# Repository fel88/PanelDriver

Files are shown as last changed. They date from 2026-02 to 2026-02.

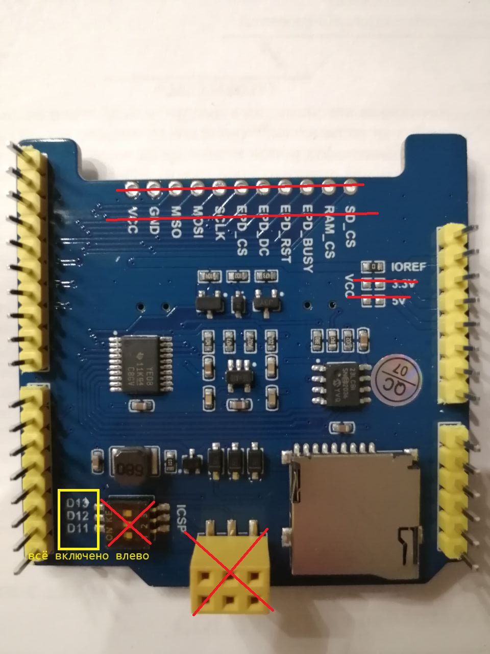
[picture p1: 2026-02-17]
docs/shield6.jpg

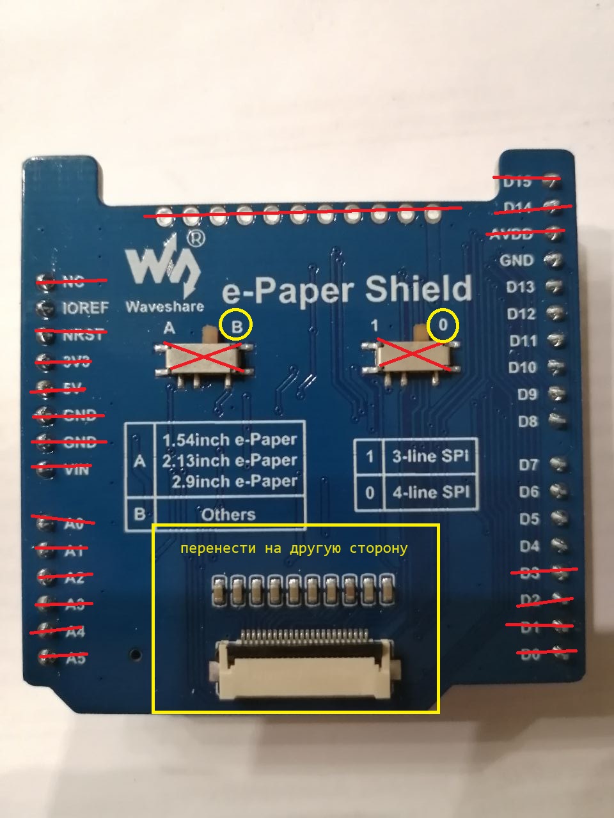
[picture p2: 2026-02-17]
docs/shield5.png

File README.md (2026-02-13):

# PanelDriver
Arduino Mega 2560 Embed + Waveshare e-ink universal shield



<h2>Parts:</h2>




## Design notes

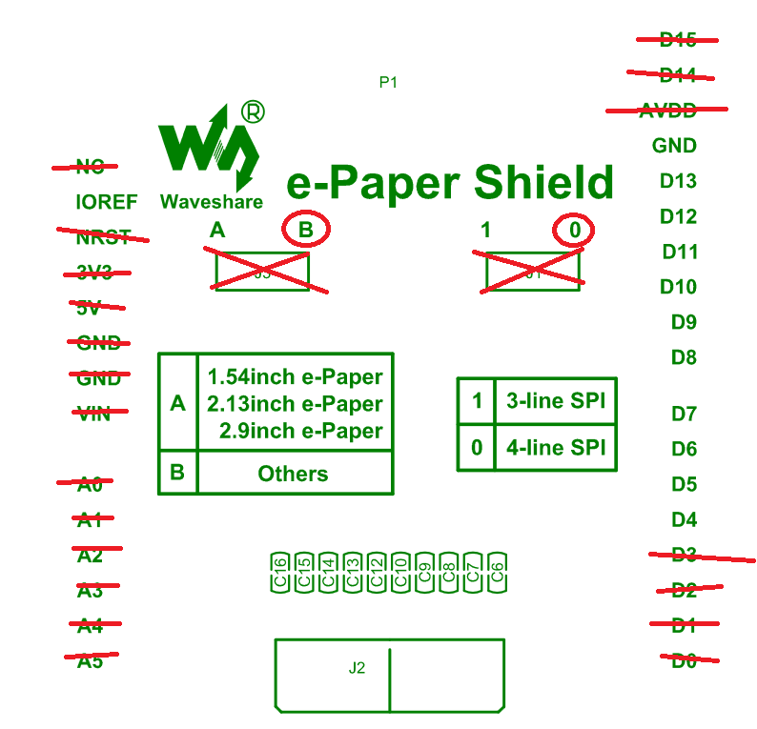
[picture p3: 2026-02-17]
docs/shield1.png

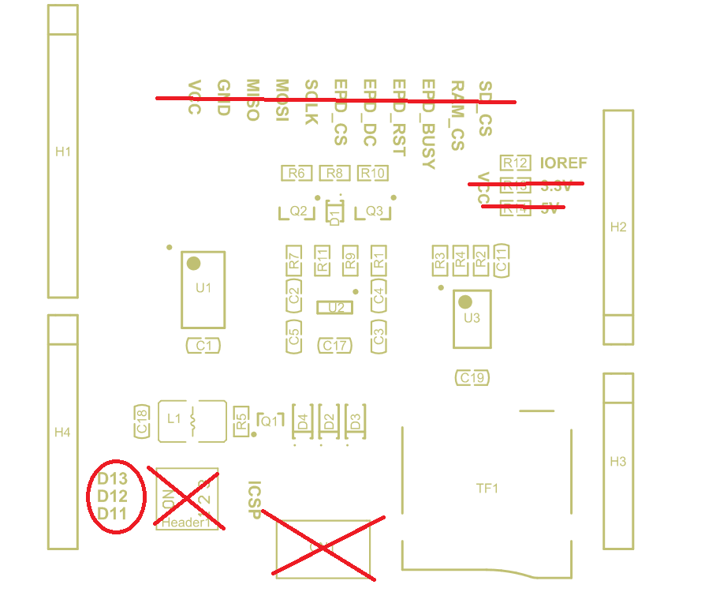
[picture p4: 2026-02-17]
docs/shield2.png

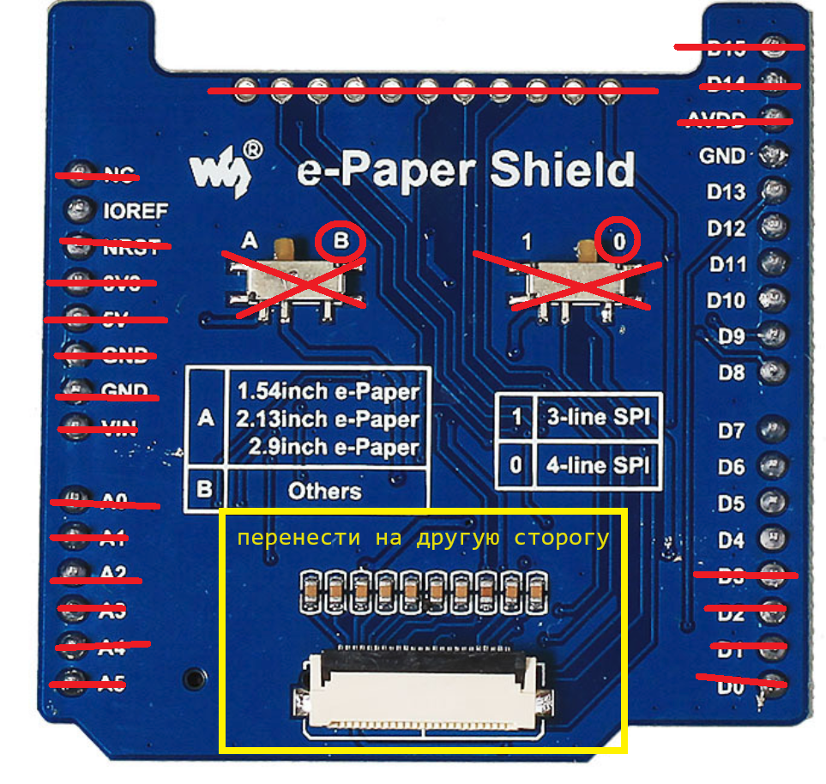
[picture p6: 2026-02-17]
docs/shield3.png

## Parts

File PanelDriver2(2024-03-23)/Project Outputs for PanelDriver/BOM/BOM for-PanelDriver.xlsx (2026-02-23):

 | Component list
 | Name: | PanelDriver.PrjPcb
 | PCB Rev: | <Parameter RevisionPCB not found>
 | BOM Variant: | None
 | Report Date: | 23.03.2024
 | Designator | Quantity | Footprint | Comment | Manufacturer | Manufacturer Part Number | Description
1 | C1, C12, C13, C18 | 4 | C0603 | 100nF | Any | Any | Capacitor
2 | C2, C3, C4, C5, C6, C7, C8, C10, C11, C14 | 10 | C0603 | 1uF | Any | Any | Capacitor
3 | C9 | 1 | C0603 | 4.7uF | Any | Any | Capacitor
4 | C15, C19 | 2 | C0603 | 100n | Any | Any | Capacitor
5 | C16 | 1 | C0603 | 22nF | Any | Any | Capacitor
6 | C17 | 1 | C0603 | 10uF | Any | Any | Capacitor
7 | C20 | 1 | C1206 | 22uF | Any | Any | 16V 22uF X7R ±10% 1206 Multilayer Ceramic Capacitors MLCC - SMD/SMT ROHS
8 | C21, C24, C25, C26, C27, C28, C29 | 7 | C0603 | 0.1uF | Any | Any | 25V 100nF X7R ±10% 0603 Multilayer Ceramic Capacitors MLCC - SMD/SMT ROHS
9 | C22, C23 | 2 | C0603 | 12pF | Any | Any | 50V 22pF X7R ±10% 0603 Multilayer Ceramic Capacitors MLCC - SMD/SMT ROHS
10 | D1, D2, D3 | 3 | SOD123 | MBR0530 | Any | MBR0530 | MBR0530
11 | D4 | 1 | SOD-323 | 1N4148WS | Any | 1N4148WS | 1N4148WS
12 | D5 | 1 | SOD123 | 1N4148W | Any | Any | 1N4148W-E3-08, Rectifier Diode Small Signal Switching Si 100V 0.15A 4ns 2-Pin SOD-123 T/R
13 | J1 | 1 | PFC24/0.5MM | PFC24/0.5MM | MOLEX | 524372471 | 24 Position FFC, FPC Connector Contacts, Bottom 0.020" (0.50mm) Surface Mount, Right Angle
14 | L1 | 1 | CD43 | 68uH | Any | Any | SMD, 4x4mm Inductor
15 | LED1, LED2, LED3, LED4 | 4 | LED-0603-GREEN | GREEN | Any | Any | 0603 Light Emitting Diodes (LED) ROHS
16 | P1, P2 | 2 | HDR1X2 | Header 2 |  |  | Header, 2-Pin
17 | P3, P4, P5 | 3 | HDR1X4 | Header 4 |  |  | Header, 4-Pin
18 | P6 | 1 | HDR1X5 | Header 5 | Any | Any | Header, 5-Pin
19 | P7 | 1 | HDR1X16 | Header 16 |  |  | Header, 16-Pin
20 | Q1 | 1 | SOT323-3 | Si1308EDL | Any | Si1308EDL | Si1308EDL
21 | Q2 | 1 | SOT-23 | AO3401 | Any | AO3401 | AO3401
22 | Q3 | 1 | SOT-23 | S8050 | Any | S8050 | S8050
23 | R1, R14, R17 | 3 | R0603 | 10k | Any | Any | Resistor, 125mW Thick Film Resistors ±100ppm/℃ ±5% 10kΩ 0603 Chip Resistor - Surface Mount ROHS
24 | R2 | 1 | R0603 | 3R | Any | Any | Resistor
25 | R3, R4, R9, R10, R13 | 5 | R0603 | 1k | Any | Any | Resistor, 125mW Thick Film Resistors ±100ppm/℃ ±5% 1kΩ 0603 Chip Resistor - Surface Mount ROHS
26 | R5, R7 | 2 | R0603 | 47k | Any | Any | Resistor
27 | R6, R8 | 2 | R0603 | 100k | Any | Any | Resistor
28 | R11, R12 | 2 | R0603 | 6.8k | Any | Any | 125mW Thick Film Resistors ±100ppm/℃ ±5% 6.8kΩ 0603 Chip Resistor - Surface Mount ROHS
29 | R15, R16 | 2 | R0603 | 22 | Any | Any | 125mW Thick Film Resistors ±100ppm/℃ ±5% 22Ω 0603 Chip Resistor - Surface Mount ROHS
30 | R18 | 1 | R0603 | 1M | Any | Any | 125mW Thick Film Resistors ±100ppm/℃ ±5% 1M 0603 Chip Resistor - Surface Mount ROHS
31 | TF1 | 1 | L-KLS1-TF-003-uSD | SD CARD | KLS electronic co ltd | L-KLS1-TF-003-uSD | SDCARD
32 | U1 | 1 | TSSOP-20_0.65mm | TXS0108EPWR | Any | TXS0108EPWR | TXS0108EPWR
33 | U2 | 1 | SO8 | 23LC1024 | Any | 23LC1024 | 23LC1024
34 | U3 | 1 | SOT23-5 | RT9193 | Any | RT9193 | RT9193
35 | U4 | 1 | TQFP100A | ATMEGA2560-16AU | Microchip Tech | ATMEGA2560-16AU | 256KB 4.5V~5.5V AVR 8KB 16MHz FLASH 86 TQFP-100(14x14) Microcontroller Units (MCUs/MPUs/SOCs) ROHS
36 | Y1 | 1 | HC-49/US-SMD | 16MHz | Any | Any | Crystal 16MHz 12pF SMD
 | TOTAL PART COUNT: | 74

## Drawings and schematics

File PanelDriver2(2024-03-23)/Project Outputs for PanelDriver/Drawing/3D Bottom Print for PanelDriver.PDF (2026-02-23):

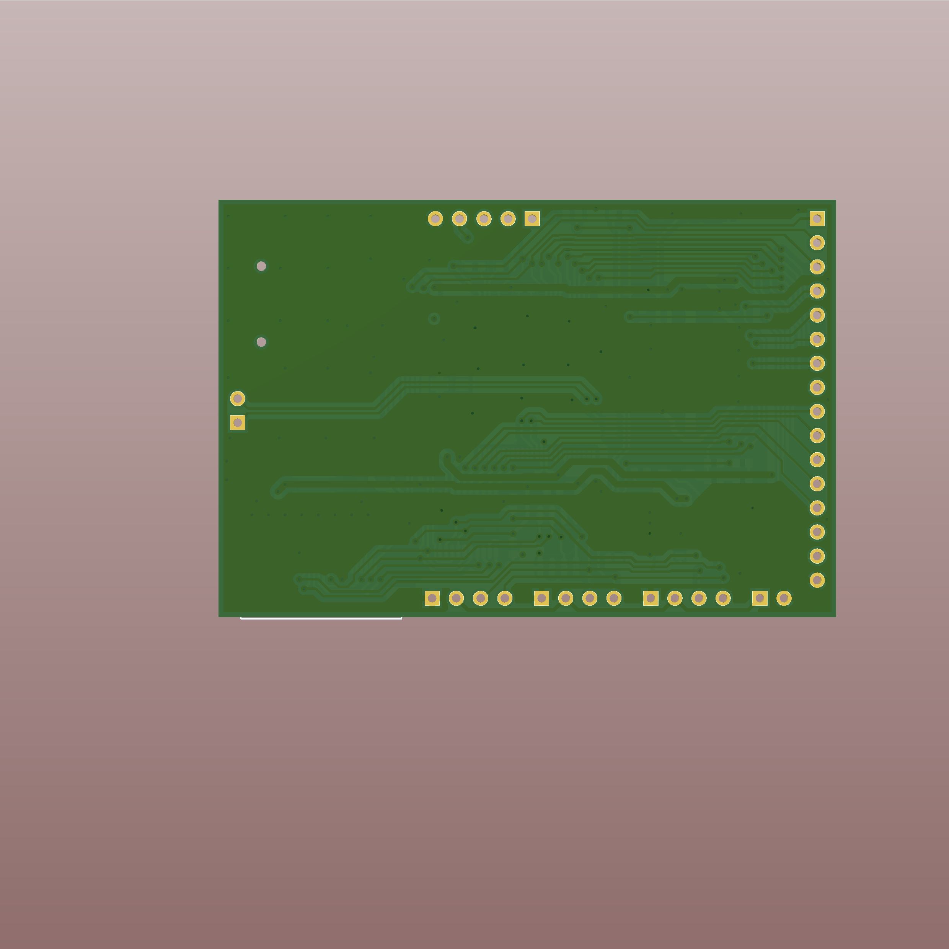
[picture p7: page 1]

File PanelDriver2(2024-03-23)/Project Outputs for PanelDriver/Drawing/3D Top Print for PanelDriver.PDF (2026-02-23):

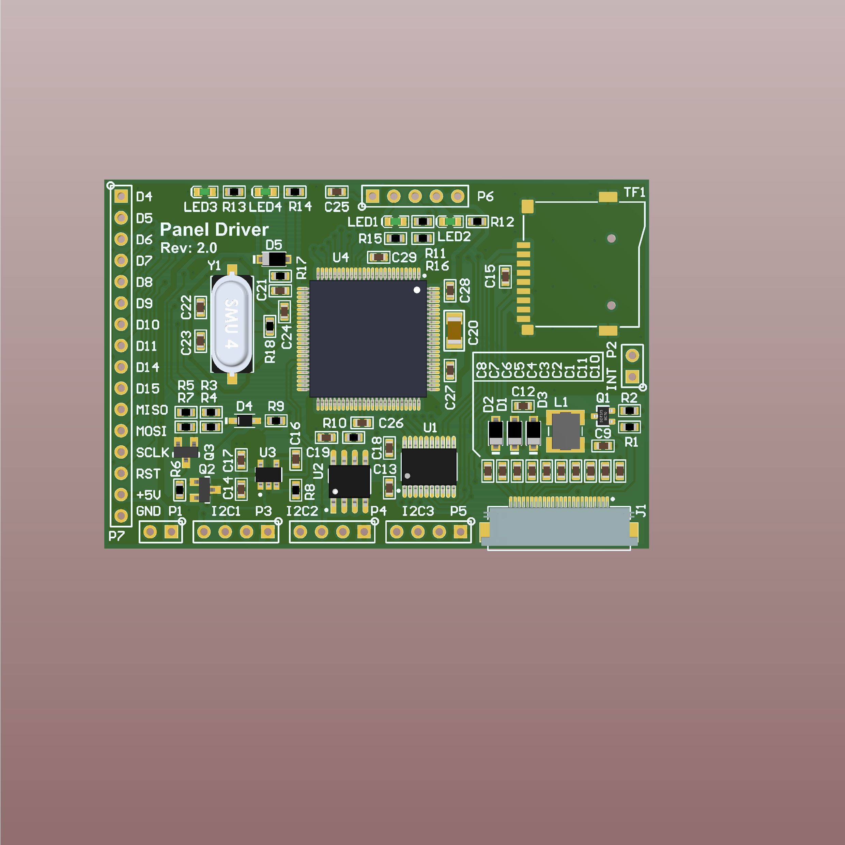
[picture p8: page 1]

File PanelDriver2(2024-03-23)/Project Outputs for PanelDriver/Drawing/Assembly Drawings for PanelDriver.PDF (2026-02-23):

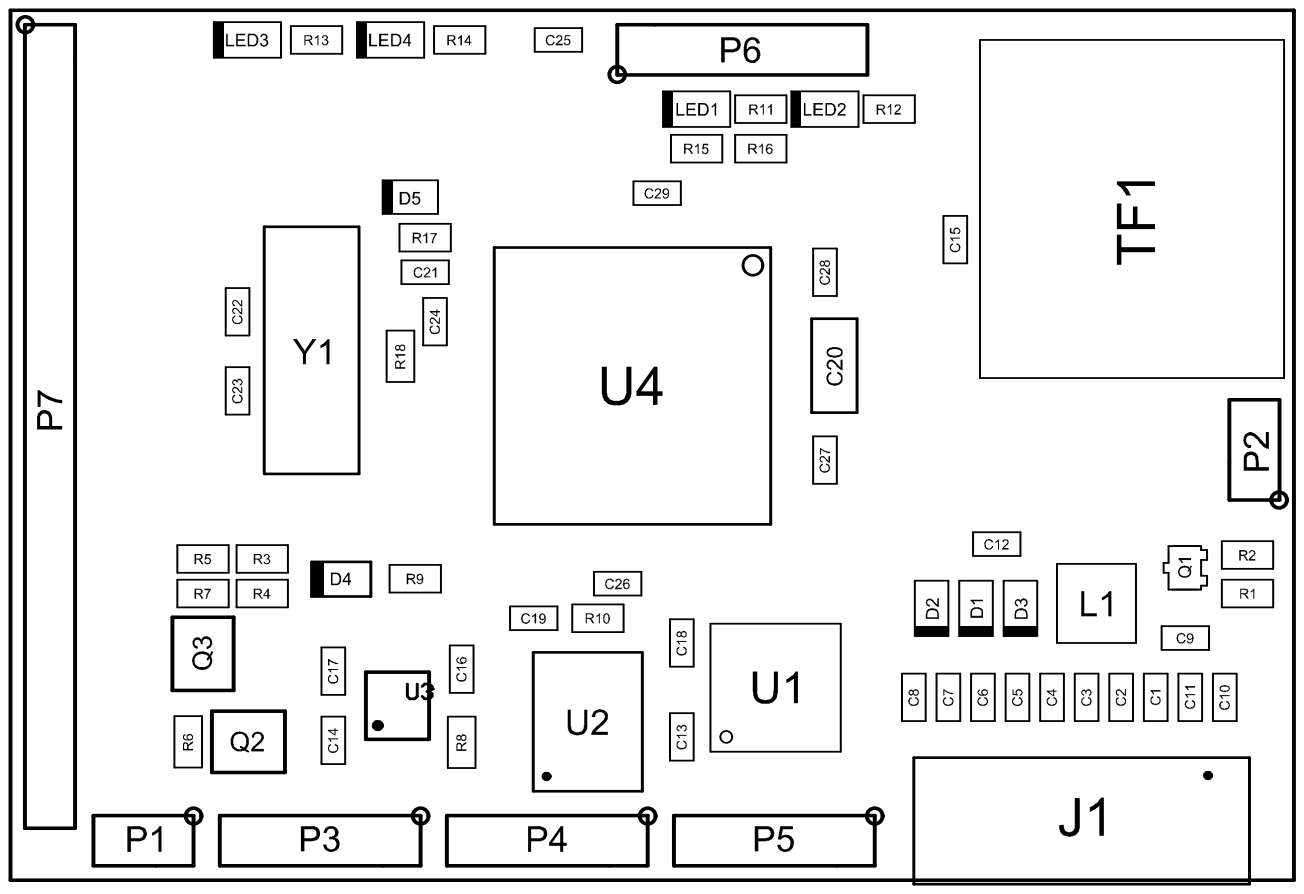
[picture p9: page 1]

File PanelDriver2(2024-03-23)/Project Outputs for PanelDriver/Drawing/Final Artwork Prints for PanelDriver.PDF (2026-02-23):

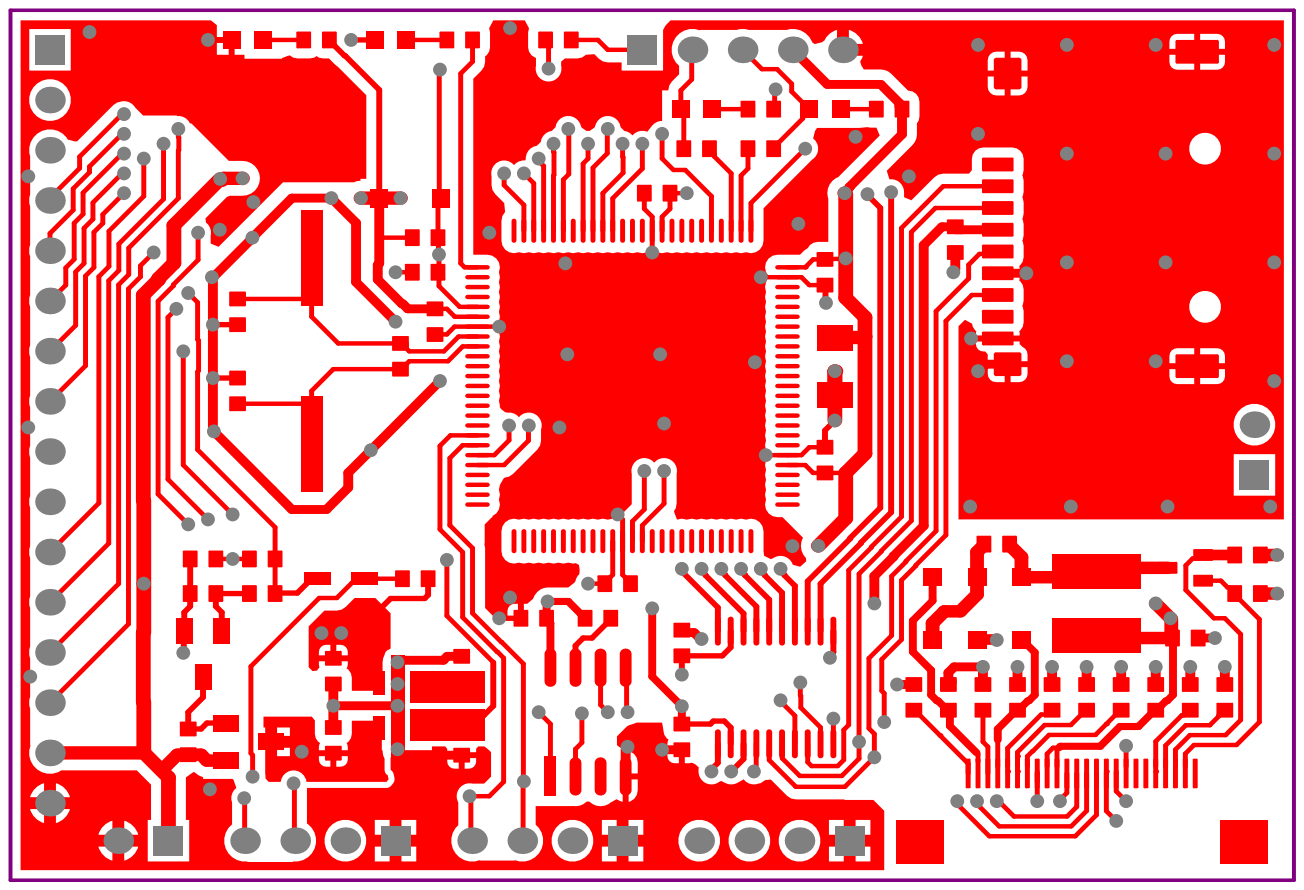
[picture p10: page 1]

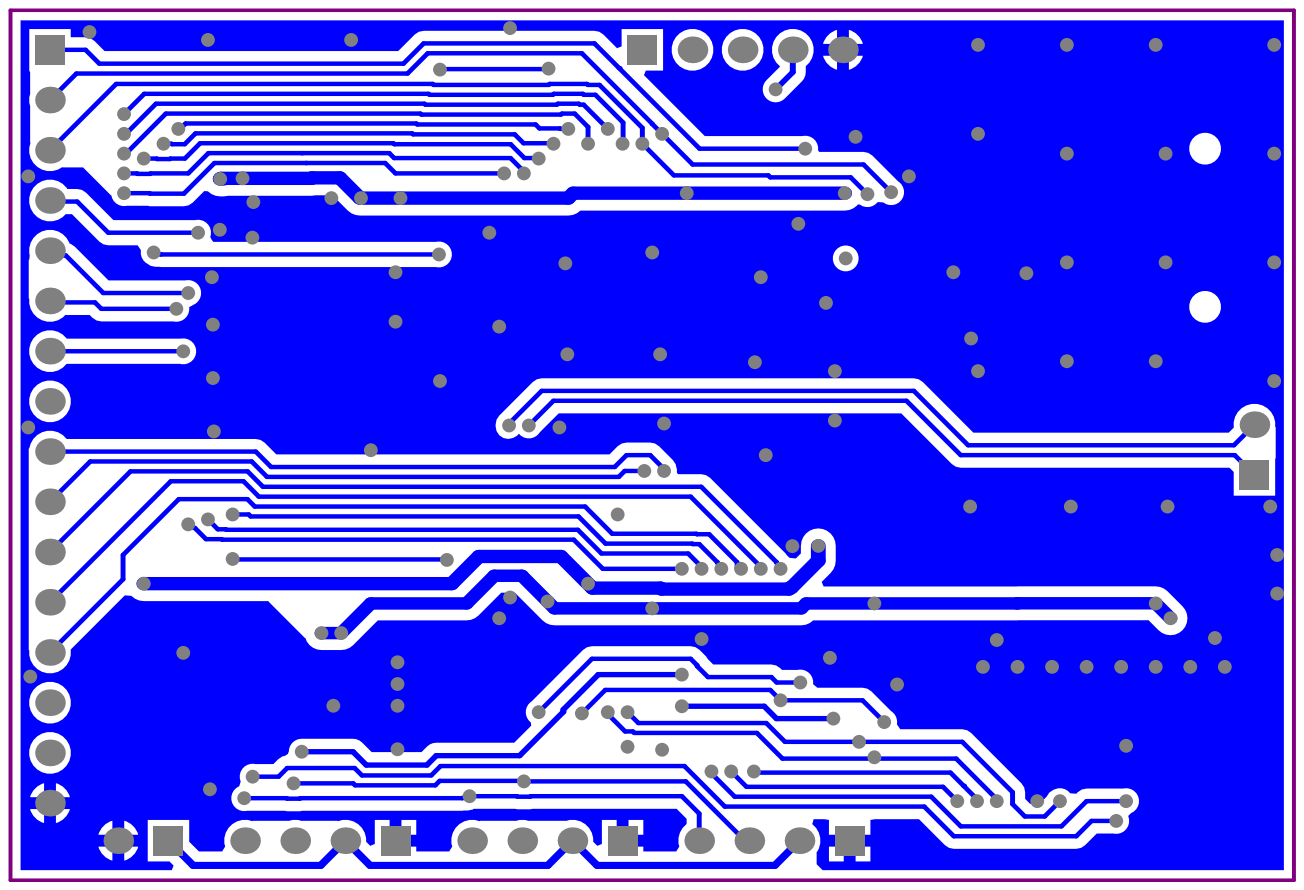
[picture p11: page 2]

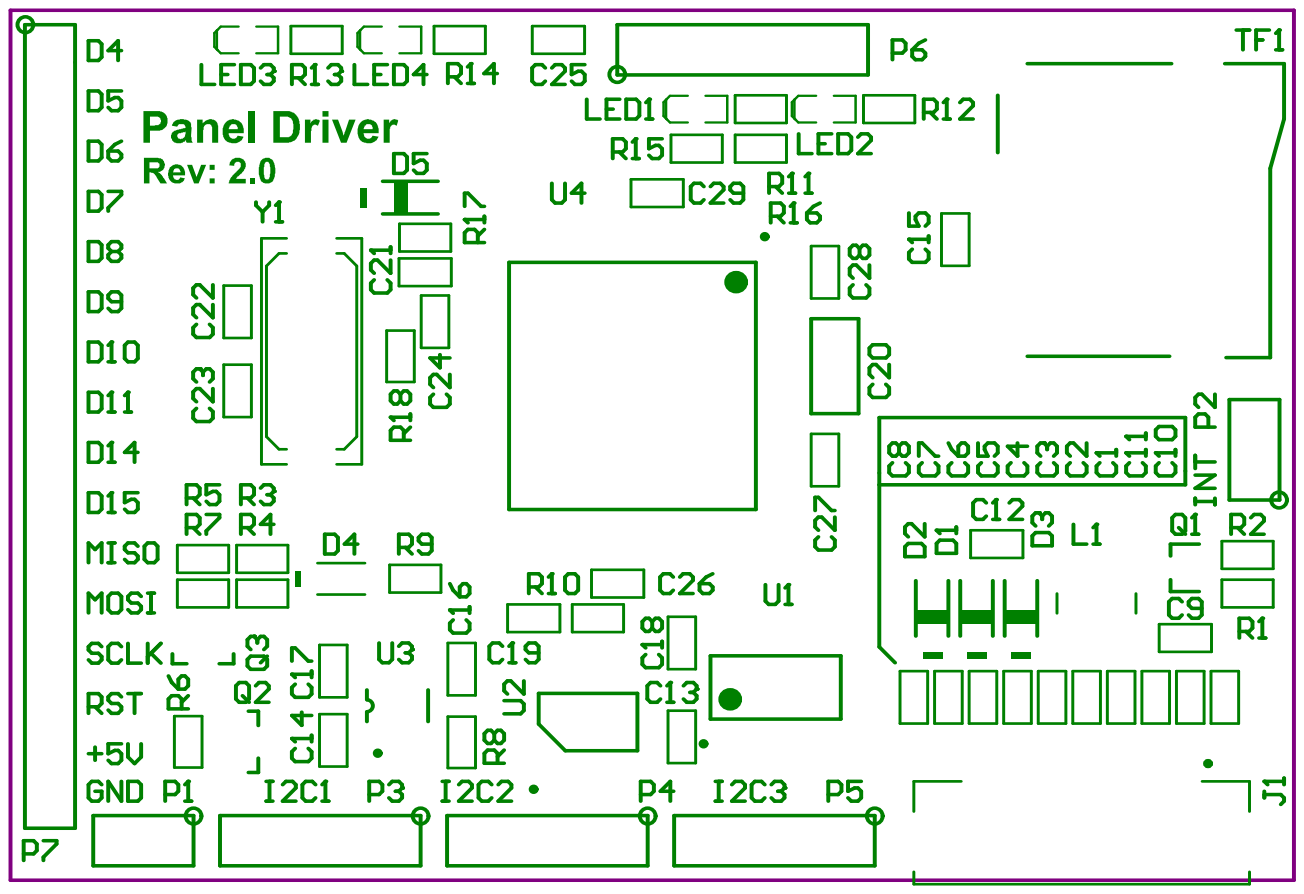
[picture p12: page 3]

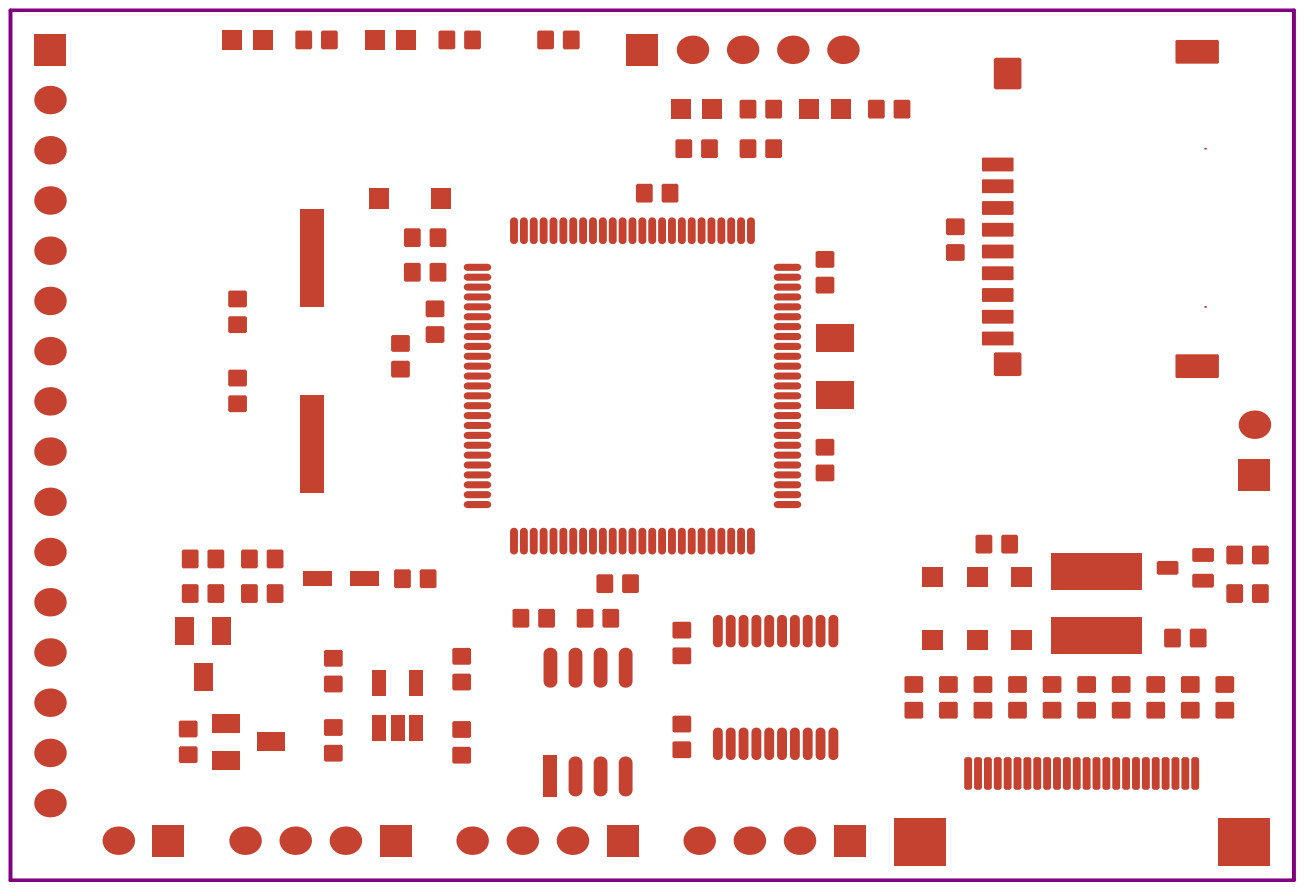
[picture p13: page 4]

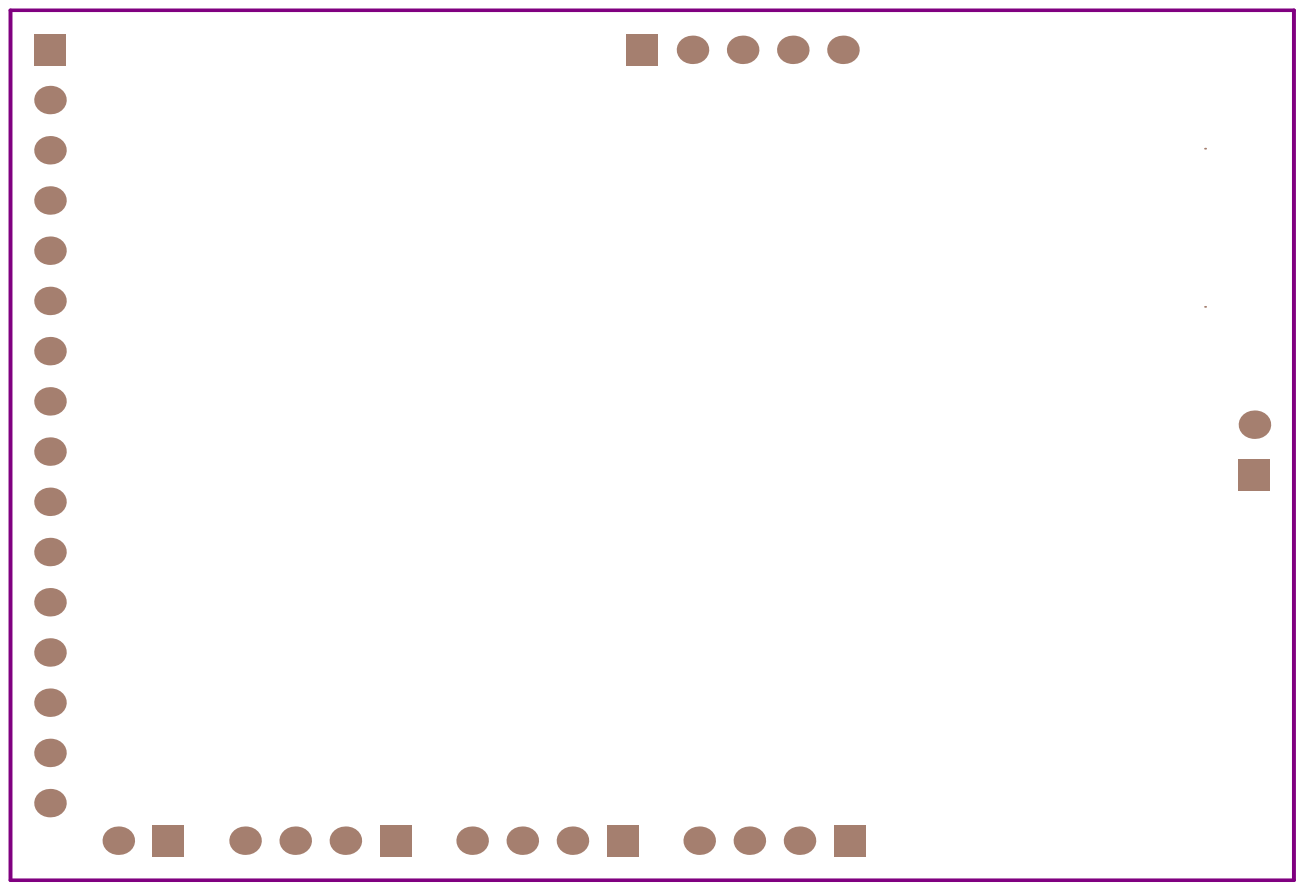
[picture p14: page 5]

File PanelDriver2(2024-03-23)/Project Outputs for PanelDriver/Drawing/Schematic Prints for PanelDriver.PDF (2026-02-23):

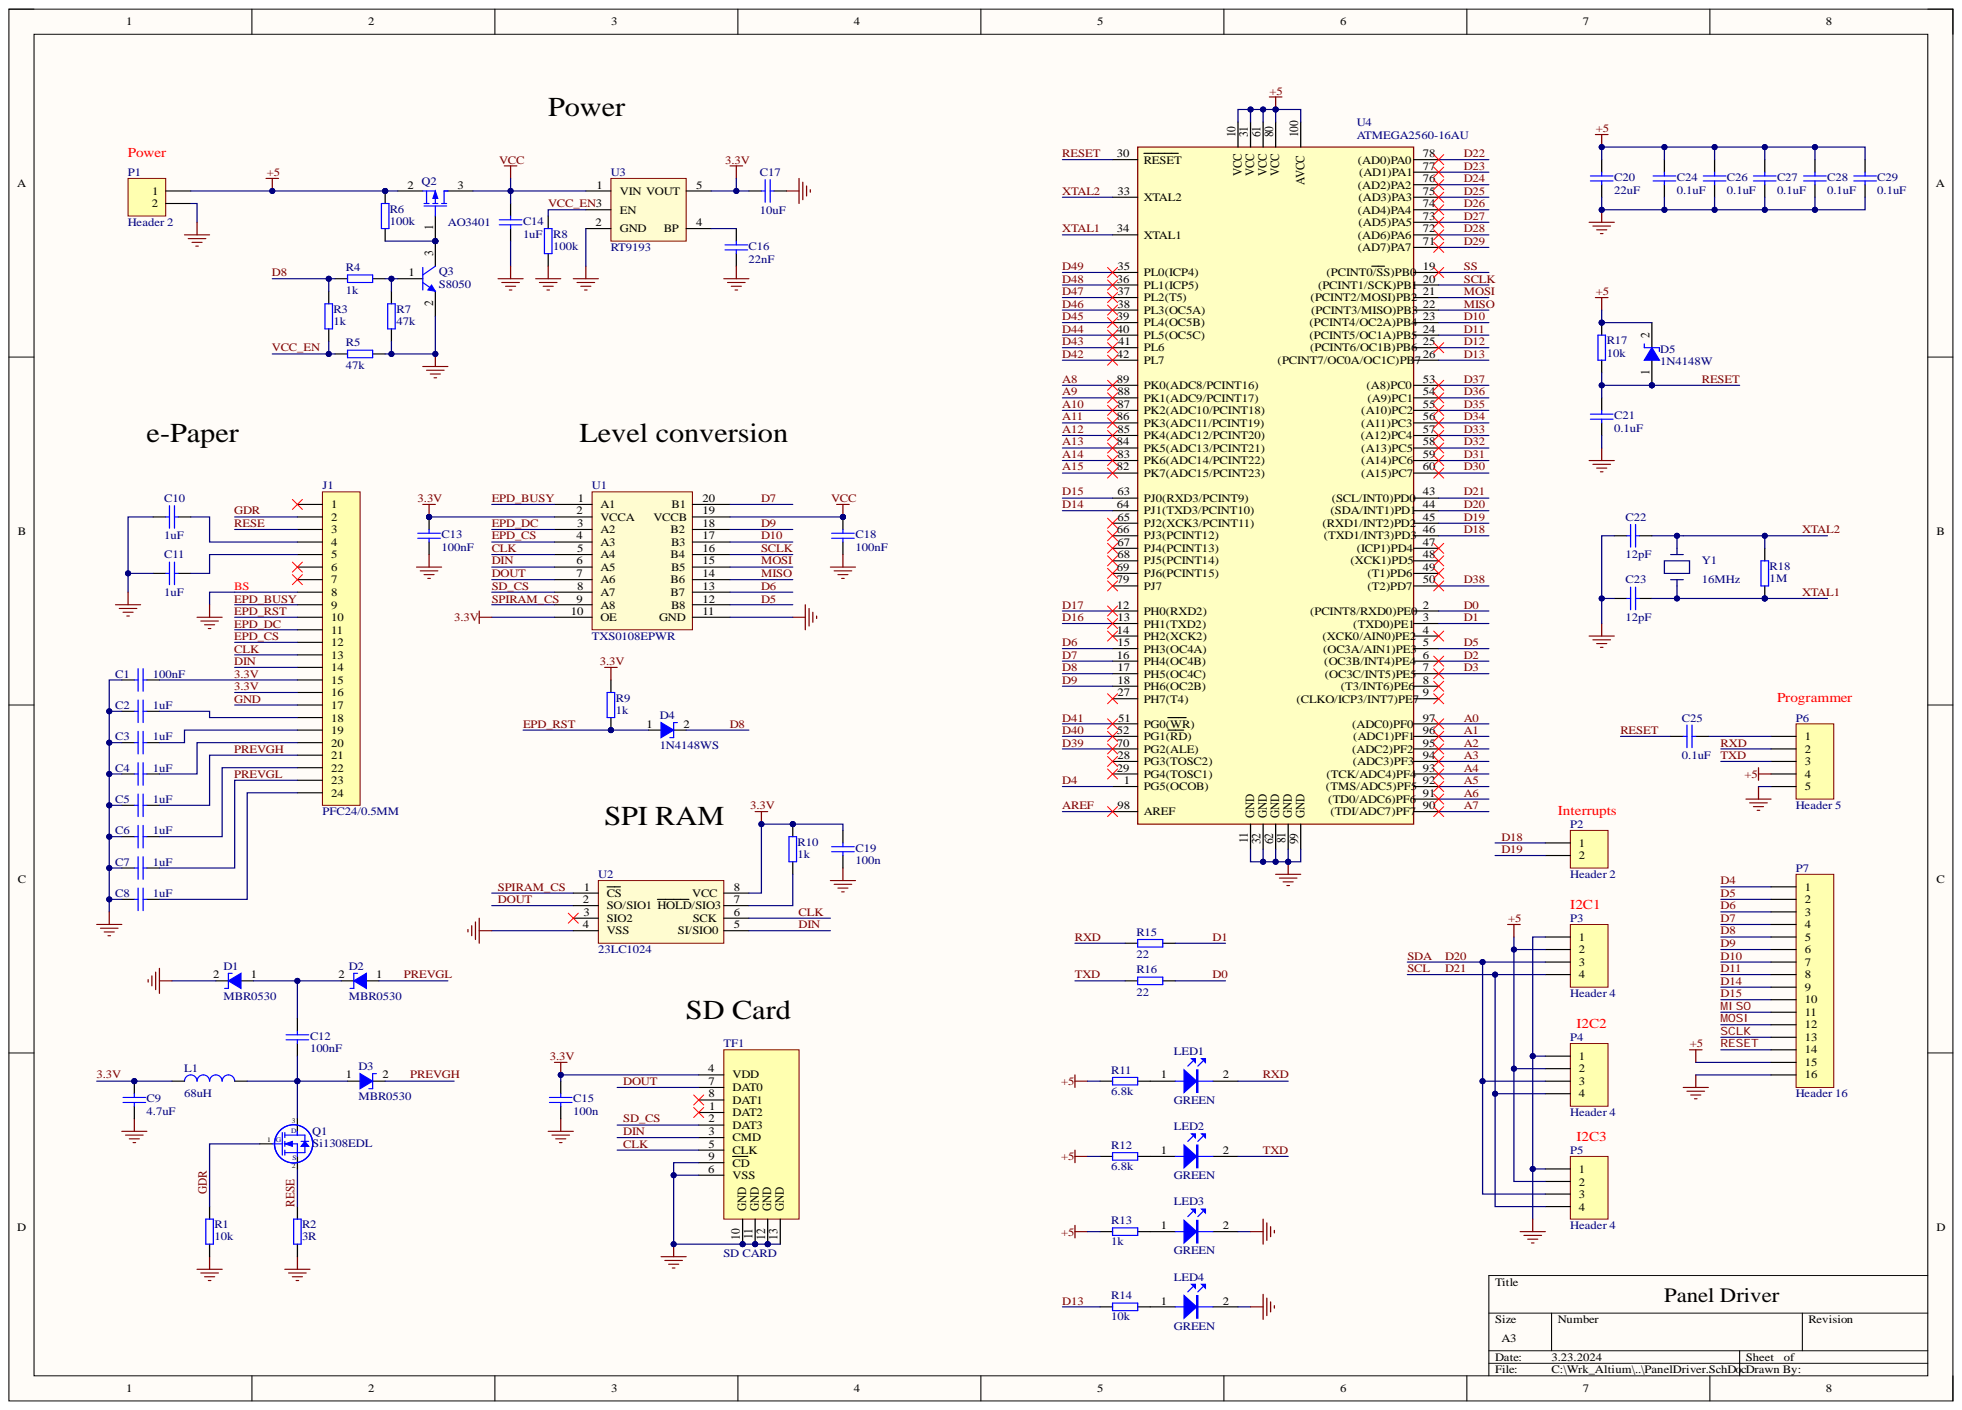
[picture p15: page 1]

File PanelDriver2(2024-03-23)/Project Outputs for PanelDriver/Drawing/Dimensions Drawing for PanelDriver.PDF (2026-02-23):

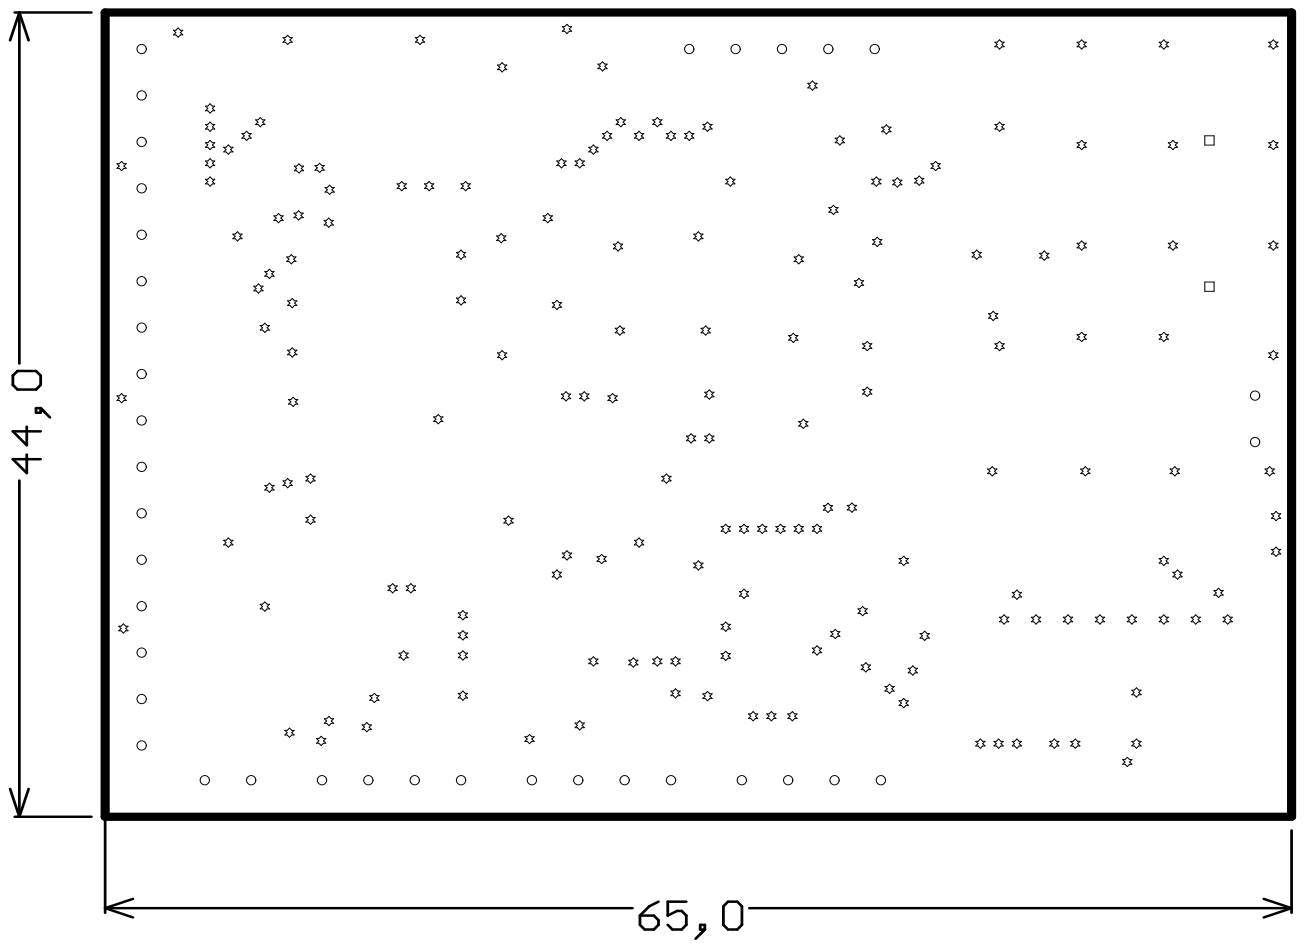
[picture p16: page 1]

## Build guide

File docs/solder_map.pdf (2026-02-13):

Sheet1
panel driver | | waveshare
R10 | 1K | R2
C19 | 100nF C11
C15 | 100nF C19
C1 | 100nF C8
C10 | 1uF | C6
C11 | 1uF | C7
C2 | 1uF | C9
C3 | 1uF | C10
C4 | 1uF | C12
C5 | 1uF | C13
C6 | 1uF | C14
C7 | 1uF | C15
C8 | 1uF | C16
C13 | 100nF C1
C18 | 100nF C2
D4 | | D1
R9 | 1K | R1
U3 | | U2
C17 | | C3
C16 | | C5
R8 | | R7
C14 | | C4
Q2 | | Q2
R6 | | R6
Q3 | | Q3
R4 | | R8
R3 | | R9
R5 | | R11
R7 | | R10
Q1 | | Q1
D3 | | D4
L1 | | L1

Sheet1
C9 | 4.7uF C18
C12 | 100nF C17
D2 | | D3
D1 | | D2
R2 | | R3
R1 | 10K | R5
panel driver | | mega
R11 | | R10
R12 | | R11
R13 | | R12
R14 | | R13
LED1 | | LED1
LED2 | | LED2
LED3 | | LED3
LED4 | | LED4
R15 | | R2
R16 | | R4
R17 | | R14
D5 | | D2
C21 | | C12
C25 | 0.1uF C1
C20 | 22uF | C11
C24 | 0.1uF C6
C26 | 0.1uF C7
C27 | 0.1uF C8
C28 | 0.1uF C9
C29 | 0.1uF C10
U4 | | U4
Y1 | 16Mhz Y2
C22 | 12pF | C13
C23 | 12pF | C14
R18 | 1M | R15

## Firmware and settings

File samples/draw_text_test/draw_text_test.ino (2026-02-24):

#include "EPD_My_sdfat.h"
#include "GUI_Paint.h"
#include "EPD_SDCard.h"
#include <avr/sleep.h>
#include <avr/power.h>
#include <avr/wdt.h>

#include <EEPROM.h>


#include <Wire.h>


bool screensRevert = false;


#include <Arduino.h>
#include <Wire.h>


sFONT* font = &Font12;

int fontHeight = 12;
//int cols=54;//35 for font24; 54 for font16;85 for font12
//int rows=22;//17 for font24; 27 for font16; 29 for font12(gap=3)
int cols = 80;  //35 for font24; 54 for font16;85 for font12
int rows = 25;  //17 for font24; 27 for font16; 29 for font12(gap=3)
int page = 1;
int pages = 778;
//int gap=2;
int gap = 3;
//int fontWidth=11;//11 for font16, 17 for font24, 7 for font12
int fontWidth = 7;  //11 for font16, 17 for font24, 7 for font12



UWORD Image_Width_Byte;
UWORD Bmp_Width_Byte;
int width;
int bookWidth;
int height;
int bookHeight;



extern SdFat sd;

#define MFILE_WRITE (O_RDWR | O_CREAT | O_AT_END)
#define MFILE_READ (O_RDONLY)


extern UBYTE _readBuff[801];



void fastDisplayBuffer() {
  EPD_5IN83_V2_Power(true);
  EPD_5IN83_V2_TurnOnDisplay();
}
void displayBuffer() {
  EPD_5IN83_V2_Display();
  //EPD_5IN83_Sleep();
}


void Paint_DrawString_Flow(UWORD Xstart, const unsigned char* pString,
                           sFONT* Font, UWORD Color_Background, UWORD Color_Foreground) {
  UWORD Xpoint = Xstart;


  if (Xstart > Paint_Image.Image_Width /*|| Ystart > Paint_Image.Image_Height*/) {
    DEBUG("Paint_DrawString_Flow Input exceeds the normal display range\r\n");
    return;
  }
  UBYTE Data_Black, Data;

  int indexb = 0;
  UBYTE accum = 0;
  for (int j = 0; j < Font->Height; j++)
    for (int i = 0; i < 81 * 8; i++) {
      int data = 0;
      if (i < Xstart || i >= (Xstart + strlen(pString) * Font->Width)) {
        data = WHITE;
      } else {

        data = WHITE;
        int symbolIdx = (i - Xstart) / Font->Width;
        int column = (i - Xstart) % Font->Width;
        char ch = pString[symbolIdx];
        int offset = (ch - ' ');
        if (ch > '~') {
          offset = ('~' - ' ') + (ch - 0xC0) + 1;
        }

        int Char_Offset = offset * Font->Height * (Font->Width / 8 + ((Font->Width % 8) != 0 ? 1 : 0));
        const unsigned char* ptr = &Font->table[Char_Offset];
        bool draw = false;
        UWORD Page, Column;
        for (Page = 0; Page < Font->Height; Page++) {
          for (Column = 0; Column < Font->Width; Column++) {
            if (Page == j && Column == column)
              draw = true;

            //To determine whether the font background color and screen background color is consistent
            if (FONT_BACKGROUND == Color_Background) {  //this process is to speed up the scan
              if (draw)
                if ((pgm_read_byte(ptr) & (0x80 >> (Column % 8))) != 0)

                {
                  //Paint_DrawPoint_Flow(Xpoint + Column, Ypoint + Page, Color_Foreground, DOT_PIXEL_DFT, DOT_STYLE_DFT);
                  data = Color_Foreground;
                }
            } else {
              if (draw)
                if ((pgm_read_byte(ptr) & (0x80 >> (Column % 8))) != 0) {
                  //Paint_DrawPoint_Flow(Xpoint + Column, Ypoint + Page, Color_Foreground, DOT_PIXEL_DFT, DOT_STYLE_DFT);
                  data = Color_Foreground;
                } else {
                  //Paint_DrawPoint_Flow(Xpoint + Column, Ypoint + Page, Color_Background, DOT_PIXEL_DFT, DOT_STYLE_DFT);
                  data = Color_Background;
                }
            }
            //One pixel is 8 bits
            if (Column % 8 == 7) {
              ptr++;
            }

            if (draw)
              break;
          }
          // Write a line
          if (Font->Width % 8 != 0)
            ptr++;
          if (draw)
            break;
        }
      }

      //setBit(ref accum, indexb, data == BLACK ? 1 : 0);
      if (data == BLACK)
        accum |= (1 << (7 - indexb));
      indexb++;
      if (indexb == 8) {

        indexb = 0;
        EPD_5IN83_V2_SendData(accum);
        accum = 0;
      }
    }
}


void FillWhiteLine(int lines = 1) {


  for (int i = 0; i < Image_Width_Byte * lines; i++) {
    EPD_5IN83_V2_SendData(0x00);
  }
}
void FillBlackLine(int lines = 1) {


  for (int i = 0; i < Image_Width_Byte * lines; i++) {
    EPD_5IN83_V2_SendData(0xff);
  }
}



void setup() {


  width = EPD_5IN83_V2_WIDTH;
  height = EPD_5IN83_V2_HEIGHT;
  randomSeed(analogRead(A0));
  Image_Width_Byte = (width % 8 == 0) ? (width / 8) : (width / 8 + 1);

  // clock_prescale_set(clock_div_2);

  //ADCSRA = 0;
  ADCSRA &= ~(1 << ADEN);


  rows = (448 - 1) / (gap + fontHeight) - 1;
  cols = 600 / fontWidth;

  rows -= 5;
  cols -= 5;



  initShield();
  drawTestPage();

  set_sleep_mode(SLEEP_MODE_PWR_DOWN);
  sleep_mode();
}

void initShield() {
  //digitalWrite(wemosPin,HIGH);
  //Serial3.println("sleep");


  //digitalWrite(wemosRstPin,HIGH);
  delay(500);
  DEV_Module_Init();

  EPD_5IN83_V2_Init();
  //EPD_5IN83_Clear();
  //Paint_NewImage(IMAGE_BW, EPD_5IN83_WIDTH, EPD_5IN83_HEIGHT, IMAGE_ROTATE_0, IMAGE_COLOR_INVERTED);
  Paint_NewImage(IMAGE_BW, EPD_5IN83_V2_WIDTH, EPD_5IN83_V2_HEIGHT, screensRevert ? IMAGE_ROTATE_180 : IMAGE_ROTATE_0, IMAGE_COLOR_INVERTED);
  /*SDCard_Init();

  if (i2ceeprom.begin(EEPROM_ADDR)) {  // you can stick the new i2c addr in here, e.g. begin(0x51);
    //Serial.println("Found I2C EEPROM");
  } else {
    //Serial.println("I2C EEPROM not identified ... check your connections?\r\n");
    while (1) delay(10);
  }*/
}

void preClear() {

  //2.Drawing on the image
  EPD_5IN83_V2_SendCommand(0x10);
  UBYTE ReadBuff[1] = { 0 };

  int Width = (EPD_5IN83_V2_WIDTH % 8 == 0) ? (EPD_5IN83_V2_WIDTH / 8) : (EPD_5IN83_V2_WIDTH / 8 + 1);
  int Height = EPD_5IN83_V2_HEIGHT;

  //EPD_5IN83_V2_SendCommand(0x10);
  for (int i = 0; i < Height; i++) {
    for (int j = 0; j < Width; j++) {
      EPD_5IN83_V2_SendData(0x00);
    }
  }
  EPD_5IN83_V2_SendCommand(0x13);
}

void flowDrawEnd() {

  //fastDisplayBuffer();
  EPD_5IN83_V2_TurnOnDisplay();
}





void drawTestPage() {


  EPD_5IN83_V2_Power(true);

  Paint_Clear(BLACK);
  preClear();
  int cntr = 0;


  Paint_DrawString_Flow(0, /*cntr * fontHeight,*/ "..", &Font12, WHITE, BLACK);

  cntr++;



  String filename = "hello world";

  Paint_DrawString_Flow(0, /*cntr * fontHeight,*/ filename.c_str(), &Font12, WHITE, BLACK);


  cntr++;





  //EPD_5IN83_V2_Display();
  FillWhiteLine(EPD_5IN83_V2_HEIGHT - cntr * 12);
  flowDrawEnd();
  EPD_5IN83_V2_Power(false);
}


void loop() {
}
